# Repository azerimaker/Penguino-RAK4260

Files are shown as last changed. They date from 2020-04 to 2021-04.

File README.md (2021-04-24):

# Penguino-RAK4260
This repo contains all the necessary design and fabrication files for the Penguino 4260 SAMR34 Feather breakout board. 

First prototypes are being sold on [Tindie](https://www.tindie.com/products/21143/) and some more info can also be found on the corresponding [hackaday.io](https://hackaday.io/project/168876-penguino-feather-samr34-lora-dev-board) project page. This Penguino version uses [RAK4260](https://rakwireless.kckb.st/9e150da0) module. 

________________________________

### Current HW version is:
Penguino Feather v1.2. 
- Comes with green soldermask
- Adds CH340E USB-UART Converter IC

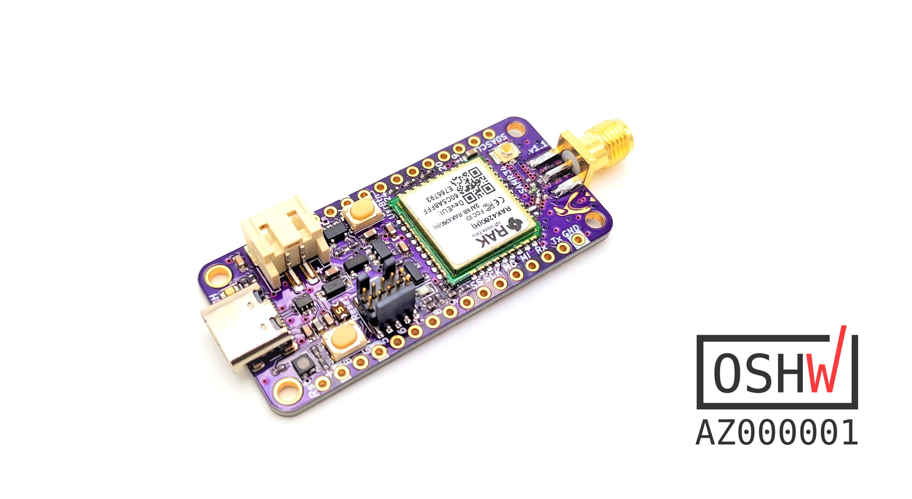
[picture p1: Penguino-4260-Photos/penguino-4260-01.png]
Penguino Feather Breakout v1.1


________________________________

### Example Firmware

Povided example in the *Firmware* directory contains ready to use example projetcs for Atmel Studio v7.
- RGB LED Toggle 
- LoRaWAN UART Demo

## License:
- Hardware license: CERN-OHL-S v2
- Software license: under MIT unless otherise indicated 
- Documentation license:  CC BY-SA 4.0 International.
________________________________
## Open Source Hardware
This board is an OSHWA approved design: [AZ000001](https://certification.oshwa.org/az000001.html)

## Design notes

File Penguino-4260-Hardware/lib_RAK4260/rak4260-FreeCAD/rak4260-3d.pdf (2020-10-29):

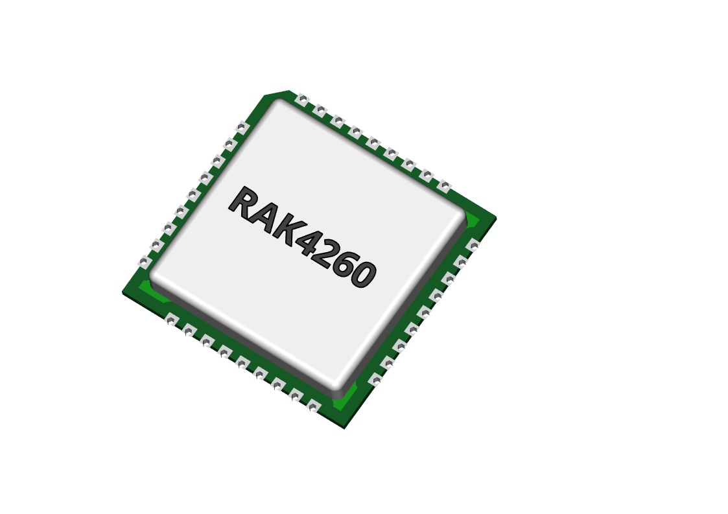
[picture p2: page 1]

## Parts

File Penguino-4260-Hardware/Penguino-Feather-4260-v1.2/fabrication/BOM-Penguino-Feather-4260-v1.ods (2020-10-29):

Name: | Penguino-Feather-4260-v1.2
Date:
Tool: | Eeschema (5.1.6)
Total Component Count: | 51
Unique Component Count: | 35
Item | Qty | Reference(s) | MPN | Alternative Part | Value | Footprint | URL | URL (alt)
1 | 3 | C1, C2, C3 | CL10A106MO8NQNC |  | 10uF | Capacitor_SMD:C_0603_1608Metric | https://lcsc.com/product-detail/Multilayer-Ceramic-Capacitors-MLCC-SMD-SMT_SAMSUNG_CL10A106MO8NQNC_10uF-106-20-16V_C92487.html | ~
2 | 3 | C4, C6, C9 | CC0603KRX7R9BB104 |  | 100nF | Capacitor_SMD:C_0603_1608Metric | https://lcsc.com/product-detail/Multilayer-Ceramic-Capacitors-MLCC-SMD-SMT_100nF-104-10-50V_C14663.html | ~
3 | 1 | C5 | GJM1555C1H470JB01D |  | 47pF | Capacitor_SMD:C_0402_1005Metric | https://lcsc.com/product-detail/Multilayer-Ceramic-Capacitors-MLCC-SMD-SMT_MuRata_GJM1555C1H470JB01D_47pF-470-5-50V_C161322.html | ~
4 |  | C7 | - |  | DNM | Capacitor_SMD:C_0402_1005Metric |  | ~
5 | 2 | C8, C12 | CC0603KRX7R9BB103 |  | 10nF | Capacitor_SMD:C_0603_1608Metric | https://lcsc.com/product-detail/Multilayer-Ceramic-Capacitors-MLCC-SMD-SMT_10nF-103-10-50V_C100042.html | ~
6 | 1 | C10 | CC0603KRX7R8BB105 |  | 1uF | Capacitor_SMD:C_0603_1608Metric | https://lcsc.com/product-detail/Others_YAGEO-CC0603KRX7R8BB105_C106858.html | ~
7 | 2 | C11, C13 | CC0402MRY5V8BB104 |  | 100nF | Capacitor_SMD:C_0402_1005Metric | https://lcsc.com/product-detail/Others_YAGEO-CC0402MRY5V8BB104_C327271.html | ~
8 | 1 | D1 | MBR0520 |  | MBR0520 | Diode_SMD:D_SOD-123 | https://lcsc.com/product-detail/Schottky-Barrier-Diodes-SBD_Changjiang-Electronics-Tech-CJ-MBR0520_C77335.html | ~
9 | 1 | D2 | 19-217/S2C-AL1M2VY/3T |  | CH_ORANGE | LED_SMD:LED_0603_1608Metric | https://lcsc.com/product-detail/Others_Everlight-Elec-19-217-S2C-AL1M2VY-3T_C264477.html | ~
10 | 1 | D3 | PGB1010402KR |  | PGB1010402 | Inductor_SMD:L_0402_1005Metric | https://lcsc.com/product-detail/Diodes-ESD_Littelfuse-PGB1010402KR_C10676.html | ~
11 | 1 | D4 | FC-DA1608BK-470H10 |  | PWR_BLUE | LED_SMD:LED_0603_1608Metric | https://lcsc.com/product-detail/Light-Emitting-Diodes-LED_Blue-light-SMDLED-80-100mcdatIF-10mA_C84266.html | ~
12 | 1 | D5 | FM-B2020RGBA-HG |  | RGB LED 2020 | LED_SMD:LED_Cree-PLCC4_2x2mm_CW | https://lcsc.com/product-detail/Light-Emitting-Diodes-LED_Foshan-NationStar-Optoelectronics-FM-B2020RGBA-HG_C108793.html | ~
13 | 1 | F1 | 0805L110SLYR |  | 1A | Fuse:Fuse_0805_2012Metric | https://lcsc.com/product-detail/Surface-Mount-Fuses_Littelfuse_0805L110SLYR_Littelfuse-0805L110SLYR_C207024.html | ~
14 | 1 | FB1 | BLM18HE152SN1D |  | BLM18HE152SN1D | Inductor_SMD:L_0603_1608Metric | https://lcsc.com/product-detail/Ferrite-Beads-And-Chips_muRata_BLM18HE152SN1D_1-5KR-25-at100MHz_C82155.html | ~
15 | 1 | J1 | U.FL-R-SMT-1(80) |  | U.FL-R-SMT-1 | Connector_Coaxial:U.FL_Hirose_U.FL-R-SMT-1_Vertical | https://lcsc.com/product-detail/_Hirose_U-FL-R-SMT-1-80_Hirose-HRS-U-FL-R-SMT-1-80_C88374.html | ~
16 | 1 | J2 | SMA-J-P-H-ST-EM1 |  | SMA-Edge-Mount | tinylora_v1:SMA_J_P_X_ST_EM1_EdgeMount | https://www.ebay.com/itm/293146230861 | ~
17 | 1 | J3 | TYPE-C-31-M-12 |  | USB_C_Receptacle_USB2.0 | Connector_USB:USB_C_Receptacle_Palconn_UTC16-G | https://lcsc.com/product-detail/USB-Connectors_Korean-Hroparts-Elec-TYPE-C-31-M-12_C165948.html | ~
18 | 1 | J4 | S2B-PH-SM4-TB(LF)(SN) |  | JST_PH | Connector_JST:JST_PH_S2B-PH-SM4-TB_1x02-1MP_P2.00mm_Horizontal | https://www.aliexpress.com/item/32513477927.html?spm=a2g0o.cart.0.0.696d3c00JbldTX | ~
19 | 1 | J5 | - | FTSH-105-01-F-DV-K | Male PCB Header Dual row | Connector_PinHeader_1.27mm:PinHeader_2x05_P1.27mm_Vertical_SMD | https://www.aliexpress.com/item/-/33030461496.html?spm=a2g0o.cart.0.0.24153c00ZQAOxm | https://www.digikey.com/product-detail/en/samtec-inc/FTSH-105-01-F-DV-K-TR/SAM13160CT-ND/8827915
20 | 1 | Q1 | SI2323DS-T1-E3 |  | SI2323DS | Package_TO_SOT_SMD:SOT-23 | https://lcsc.com/product-detail/MOSFET_Vishay-Intertech-SI2323DS-T1-E3_C141511.html | ~
21 |  | R1 | - | 0R | DNM | Resistor_SMD:R_0402_1005Metric | https://lcsc.com/product-detail/Chip-Resistor-Surface-Mount_0R-0R-5_C60485.html | ~
22 | 1 | R2 | RC0402JR-070RL |  | 0R | Resistor_SMD:R_0402_1005Metric | https://lcsc.com/product-detail/Chip-Resistor-Surface-Mount_0R-0R-5_C60485.html | ~
23 | 2 | R3, R5 | RC0402JR-07100KL |  | 100K | Resistor_SMD:R_0402_1005Metric | https://lcsc.com/product-detail/Chip-Resistor-Surface-Mount_100KR-104-5_C106234.html | ~
24 | 5 | R4, R7, R9, R10, R11 | RC0402FR-071K5L |  | 1K5 | Resistor_SMD:R_0402_1005Metric | https://lcsc.com/product-detail/Chip-Resistor-Surface-Mount_1-5KR-1501-1_C114759.html | ~
25 | 3 | R6, R13, R14 | RC0402FR-074K7L |  | 4K7 | Resistor_SMD:R_0402_1005Metric | https://lcsc.com/product-detail/Chip-Resistor-Surface-Mount_4-7KR-4701-1_C105871.html | ~
26 | 2 | R8, R17 | RC0402FR-0710KL |  | 10K | Resistor_SMD:R_0402_1005Metric | https://lcsc.com/product-detail/Chip-Resistor-Surface-Mount_YAGEO-RC0402FR-0710KL_C60490.html | ~
27 | 2 | R12, R15 | 0402WGF1004TCE |  | 1M | Resistor_SMD:R_0402_1005Metric | https://lcsc.com/product-detail/Chip-Resistor-Surface-Mount_Uniroyal-Elec-0402WGF1004TCE_C26083.html | ~
28 | 1 | R16 | RC0402JR-073M6L |  | 3M6 | Resistor_SMD:R_0402_1005Metric | https://lcsc.com/product-detail/Chip-Resistor-Surface-Mount_3-6MR-365-5_C137871.html | ~
29 | 2 | SW1, SW2 | SKRPACE010 |  | USR_BTN, RESET | switch-footprints:SW_Push_SKRPACE010 | https://lcsc.com/product-detail/Tactile-Switches_ALPS_SKRPACE010_SKRPACE010_C139797.html | ~
30 | 1 | U1 | MCP73831-2ACI-OT |  | LiPo battery charger IC | Package_TO_SOT_SMD:SOT-23-5 | https://lcsc.com/product-detail/PMIC-Battery-Management_Microchip-Tech-MCP73831T-2ACI-OT_C424093.html | ~
31 | 1 | U2 | S-1313D33 | ME6215C33 | +3.3V LDO Regulator | Package_TO_SOT_SMD:SOT-23-5 | https://lcsc.com/product-detail/Low-Dropout-Regulators-LDO_ME6215C33M5G_C84119.html | https://www.mouser.de/ProductDetail/ABLIC/S-1313C33-M5T1U3?qs=QrGA9tEX17PwWIi0dGVUlw==
32 | 1 | U3 | TPS3839K33DBZR | MAX809STRG | 3V Voltage Supervisor | Package_TO_SOT_SMD:SOT-23 | https://lcsc.com/product-detail/Microprocessor-Microcontroller-Supervisors_ON-Semicon_MAX809STRG_ON-Semicon-ON-MAX809STRG_C9965.html | https://lcsc.com/product-detail/PMIC-Supervisors_TI_TPS3839K33DBZR_TPS3839K33DBZR_C96333.html
33 | 1 | U4 | RAK4260 |  | RAK4260 | rak4260:RAK4260-footprint_w_solder_paste | https://store.rakwireless.com/products/rak4260-lora-module | ~
34 | 1 | U5 | NUP2202W1T2G |  | NUP2202 | Package_TO_SOT_SMD:SOT-363_SC-70-6 | https://lcsc.com/product-detail/TVS_ON-Semicon_NUP2202W1T2G_ON-Semicon-ON-NUP2202W1T2G_C89322.html | ~
35 | 1 | U7 | ATECC608A-TNGLORAS-B |  | TTN Secure Element | Package_SO:SOIC-8_3.9x4.9mm_P1.27mm | https://www.microchipdirect.com/product/ATECC608A-TNGLORA | ~
36 | 1 | U8 | W25Q16JVSS |  | 2MB Flash Memory | Package_SO:SOIC-8_5.23x5.23mm_P1.27mm | https://lcsc.com/product-detail/FLASH_Winbond-Elec-W25Q16JVSSIQ_C82317.html | ~
37 | 1 | U9 | CH340E |  | USB UART Converter | Package_SO:MSOP-10_3x3mm_P0.5mm

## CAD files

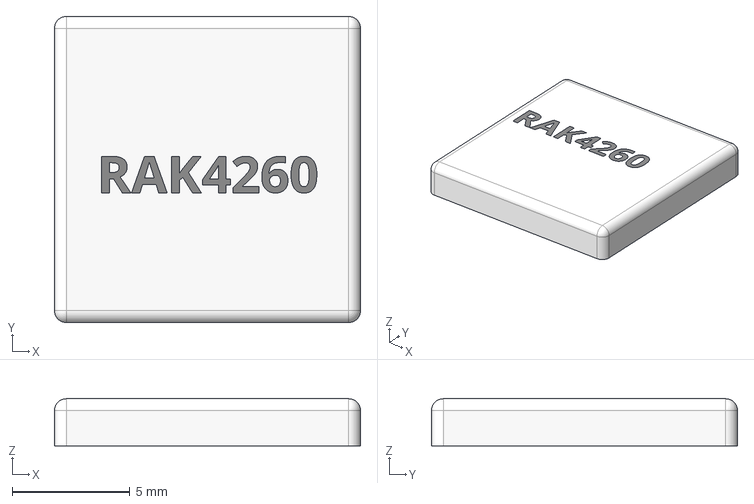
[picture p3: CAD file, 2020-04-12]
Penguino-4260-Hardware/lib_RAK4260/rak4260-FreeCAD/rak4260-freeCad.FCStd
13.0 x 13.0 x 3.00 mm
ShapeString

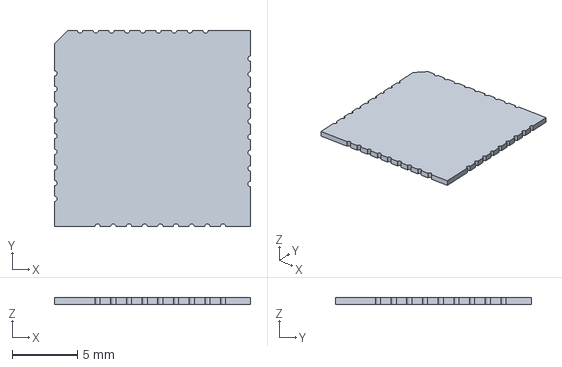
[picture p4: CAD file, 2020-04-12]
Penguino-4260-Hardware/lib_RAK4260/rak4260-pcb/radk4260-pcb.step
15.0 x 15.0 x 0.5 mm

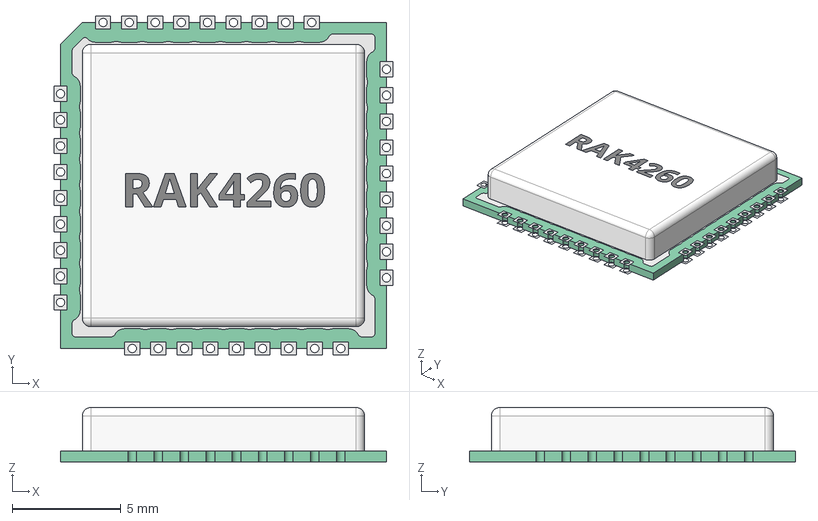
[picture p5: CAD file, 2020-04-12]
Penguino-4260-Hardware/lib_RAK4260/rak4260-FreeCAD/rak4260-freeCad-2.FCStd
15.6 x 15.6 x 2.57 mm
Pcb
topTracks
ShapeString
botTracks001

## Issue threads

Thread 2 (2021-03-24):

Battery voltage

henriAbel, 2021-03-24:
I have been experimenting with reading battery voltage using both Mbed OS and ASF framework but have not been able to get correct results. There seems to be some ADC init error in Mbed OS, I always get 0xFF as voltage. In ASF I was able to get ADC to measure something. Initially I got also max voltage but then i discovered that if i measure with multimeter between JP4 and GND and at the same time look the ADC measurement then voltage seems to be correct. I was able to reproduce same result with previous version of this board. Is there some internal pull-ups that i should disable for PA08 pin?

azerimaker, 2021-03-25:
Dear @henriAbel, thank you for bringing up this issue.
To be honest, I've never tried the ADC myself. I suspect this might be due to the selection of the reference voltage.
I would suggest using the [BastWAN sensor example](https://github.com/ElectronicCats/BastWAN/tree/master/Examples/LoRaWAN/lorawan_sensors) with Arduino IDE and see if you're able to get correct readings. There's an example sketch with ADC read function. Whenever I get I chance, I'll also look into that.

henriAbel, 2021-04-03:
BastWAN sensor example does not use ADC, just generates random values. But i flashed BastWAN Arduino core to the Penguino board and got correct results. So the problem is in my ASF code, have to poke around litte bit more.

Closed 2021-04-03.

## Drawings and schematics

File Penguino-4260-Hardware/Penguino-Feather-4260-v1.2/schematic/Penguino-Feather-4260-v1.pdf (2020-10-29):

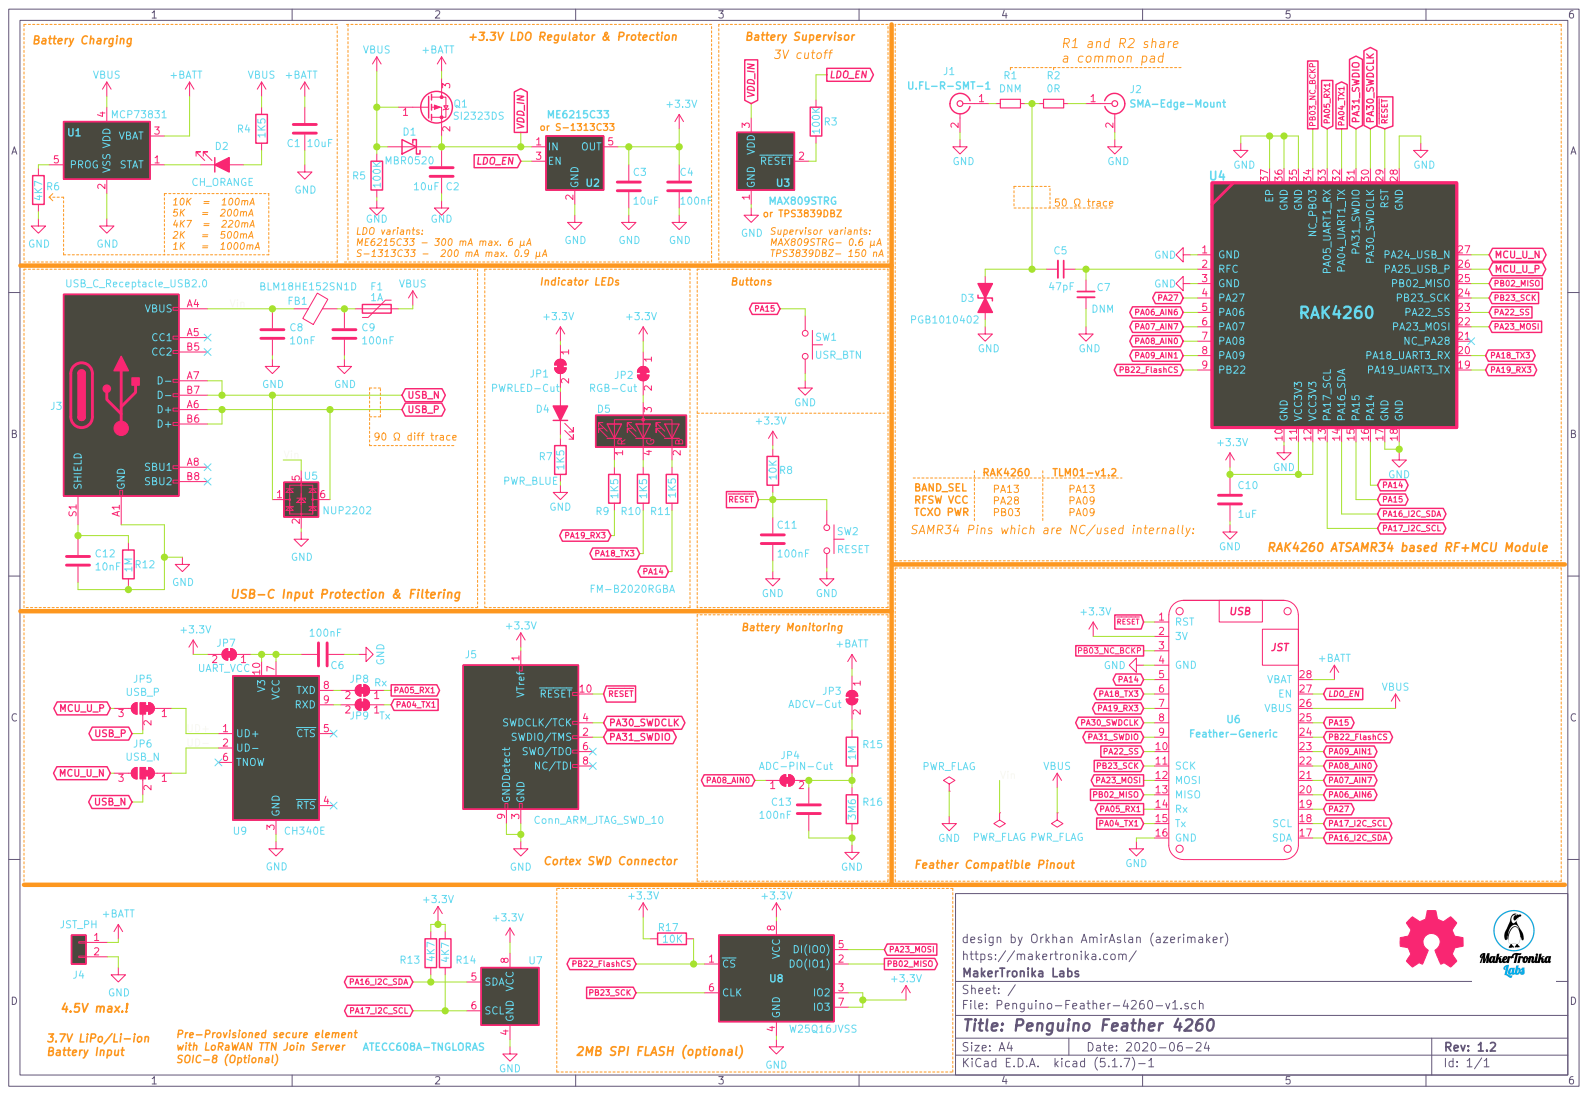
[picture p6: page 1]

50 trace Battery Supervisor Buttons Battery Charging

2 EN 3 OUT 5 U2 ME6215C33 STAT 1 VSS

USB-C Input Protection & Filtering

3 RTS 4 CTS 5 TNOW 6 VCC

3 SWDCLK/TCK 4 SWO/TDO 6 NC/TDI 8 GNDDetect 9

design by Orkhan AmirAslan (azerimaker) C13

https://makertronika.com/
File: Penguino-Feather-4260-v1.sch Sheet: / MakerTronika Labs

Id: 1/1 Title: Penguino Feather 4260

Pre-Provisioned secure element with LoRaWAN TTN Join Server SOIC-8 (Optional)

3.7V LiPo/Li-ion Battery Input

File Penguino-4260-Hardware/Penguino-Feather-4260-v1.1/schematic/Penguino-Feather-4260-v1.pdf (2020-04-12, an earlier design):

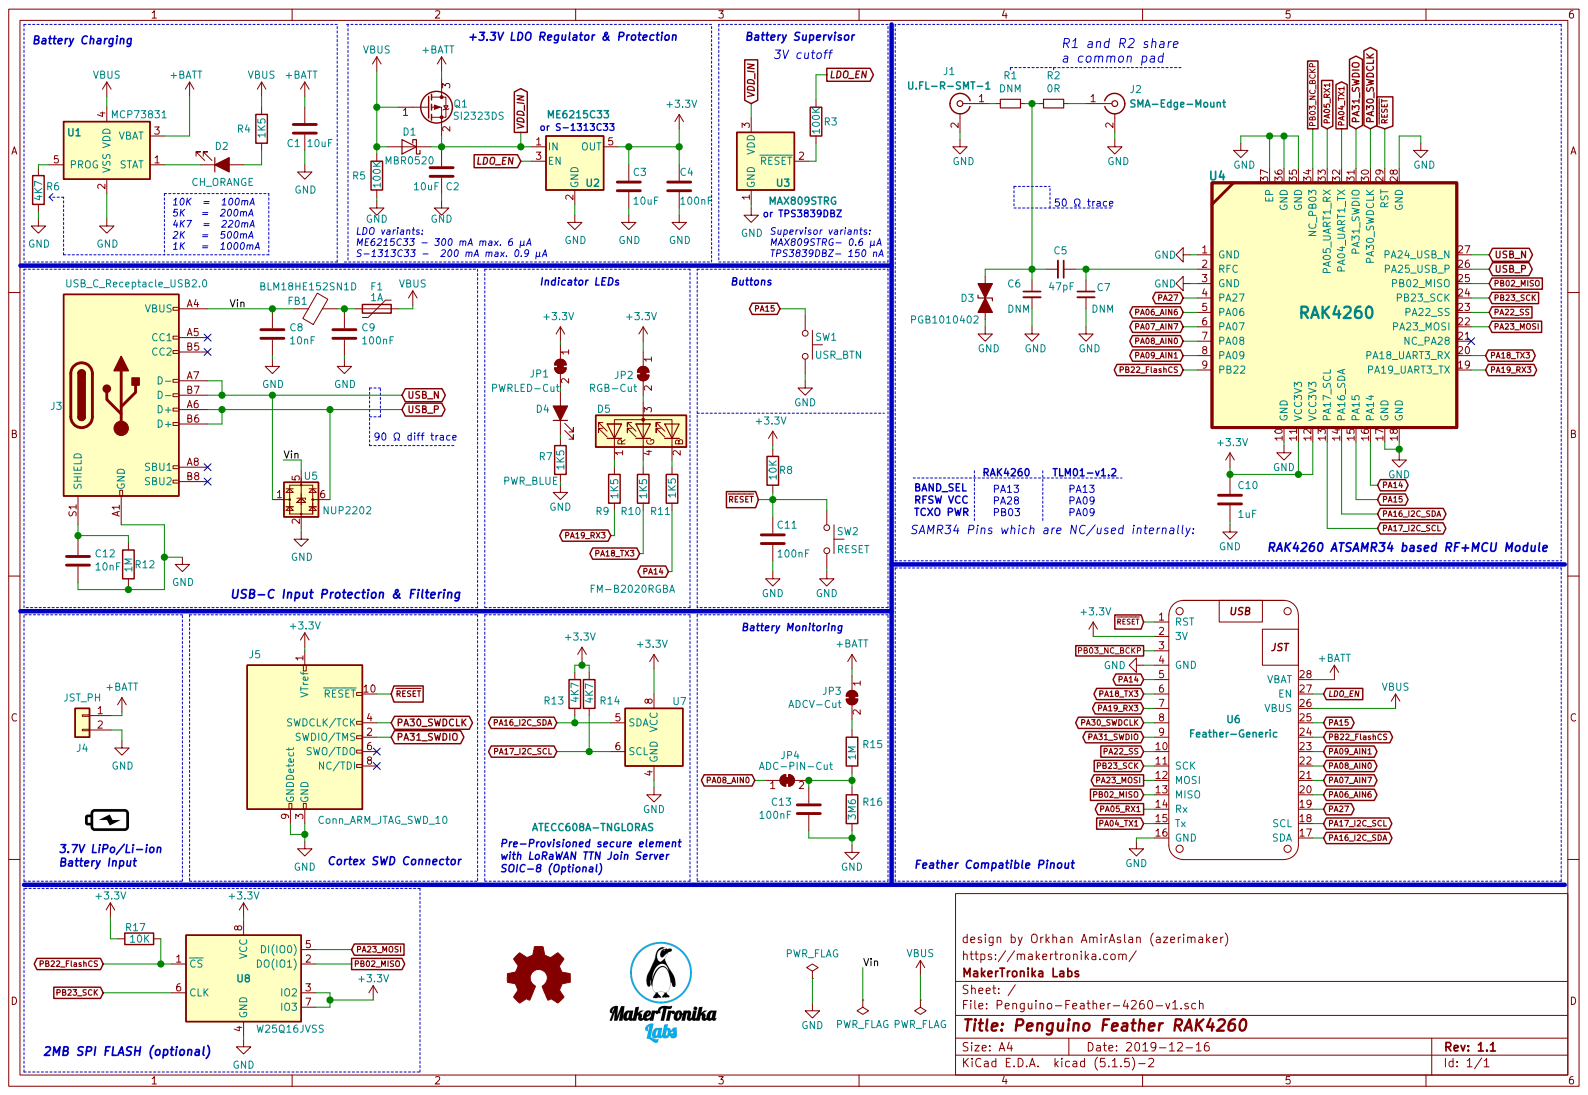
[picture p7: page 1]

2 EN 3 OUT 5 U2 ME6215C33 GND GND GND GND GND GND GND

USB-C Input Protection & Filtering

3 SWDCLK/TCK 4 SWO/TDO 6 NC/TDI 8 GNDDetect 9

3.7V LiPo/Li-ion Battery Input

design by Orkhan AmirAslan (azerimaker)
https://makertronika.com/
File: Penguino-Feather-4260-v1.sch Sheet: / MakerTronika Labs

Id: 1/1 Title: Penguino Feather RAK4260

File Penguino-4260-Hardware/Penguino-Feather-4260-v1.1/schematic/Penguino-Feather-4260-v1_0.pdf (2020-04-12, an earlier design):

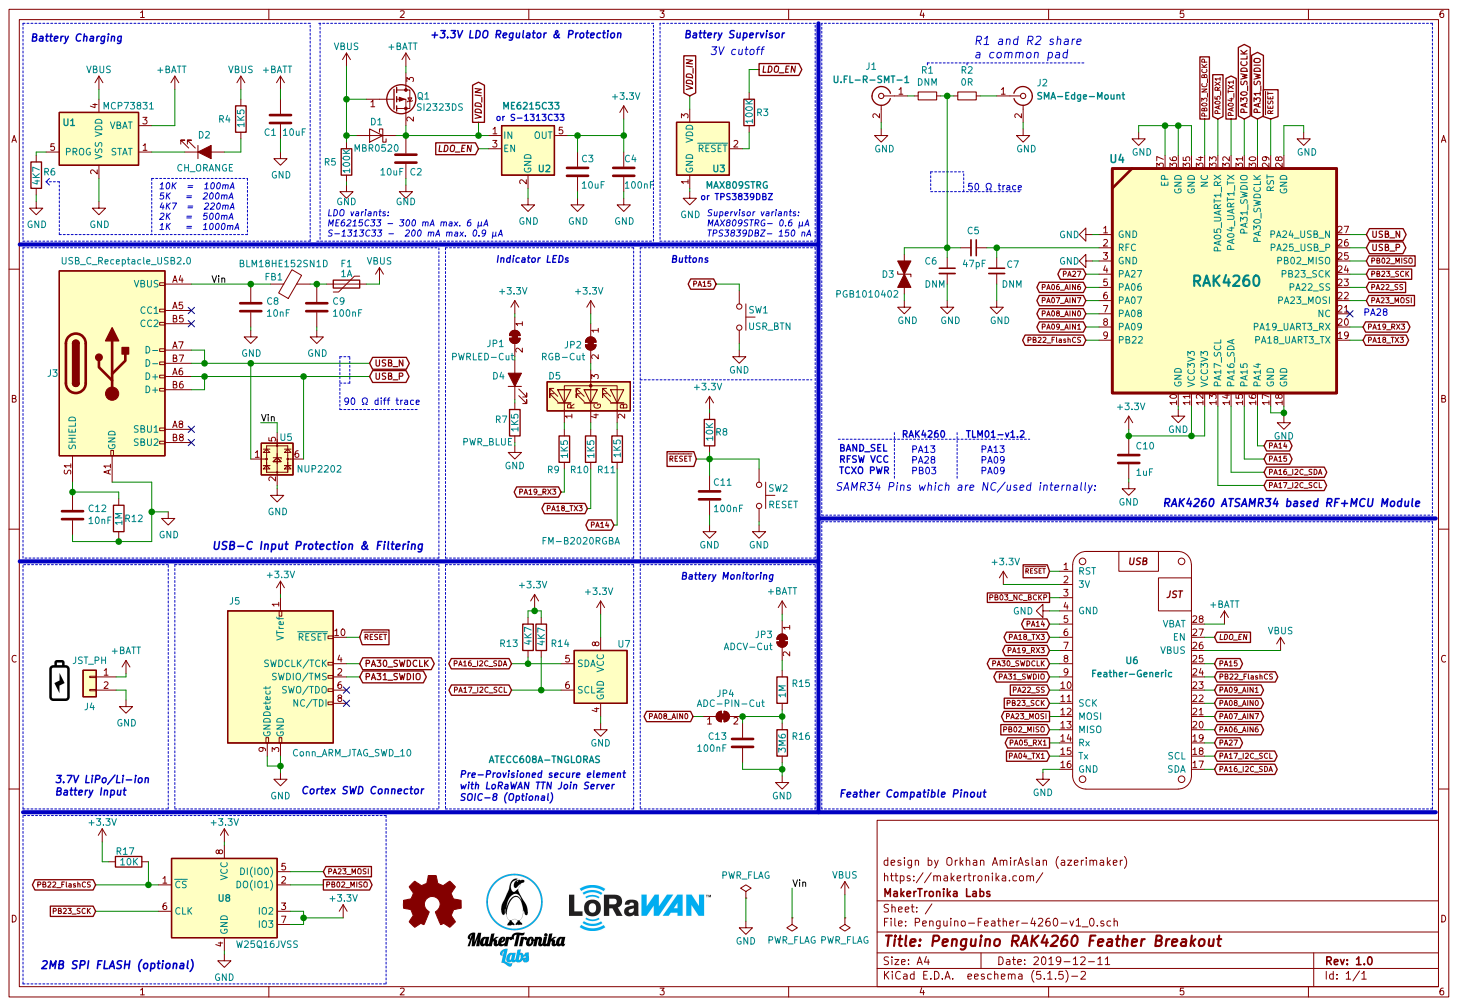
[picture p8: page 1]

2 EN 3 OUT 5 U2 ME6215C33 STAT 1 VSS

design by Orkhan AmirAslan (azerimaker) GND

JP2 RGB-Cut +BATT GND

USB-C Input Protection & Filtering

3 SWDCLK/TCK 4 SWO/TDO 6 NC/TDI 8 GNDDetect 9

3.7V LiPo/Li-ion Battery Input

https://makertronika.com/
File: Penguino-Feather-4260-v1_0.sch Sheet: / MakerTronika Labs

Id: 1/1 Title: Penguino RAK4260 Feather Breakout

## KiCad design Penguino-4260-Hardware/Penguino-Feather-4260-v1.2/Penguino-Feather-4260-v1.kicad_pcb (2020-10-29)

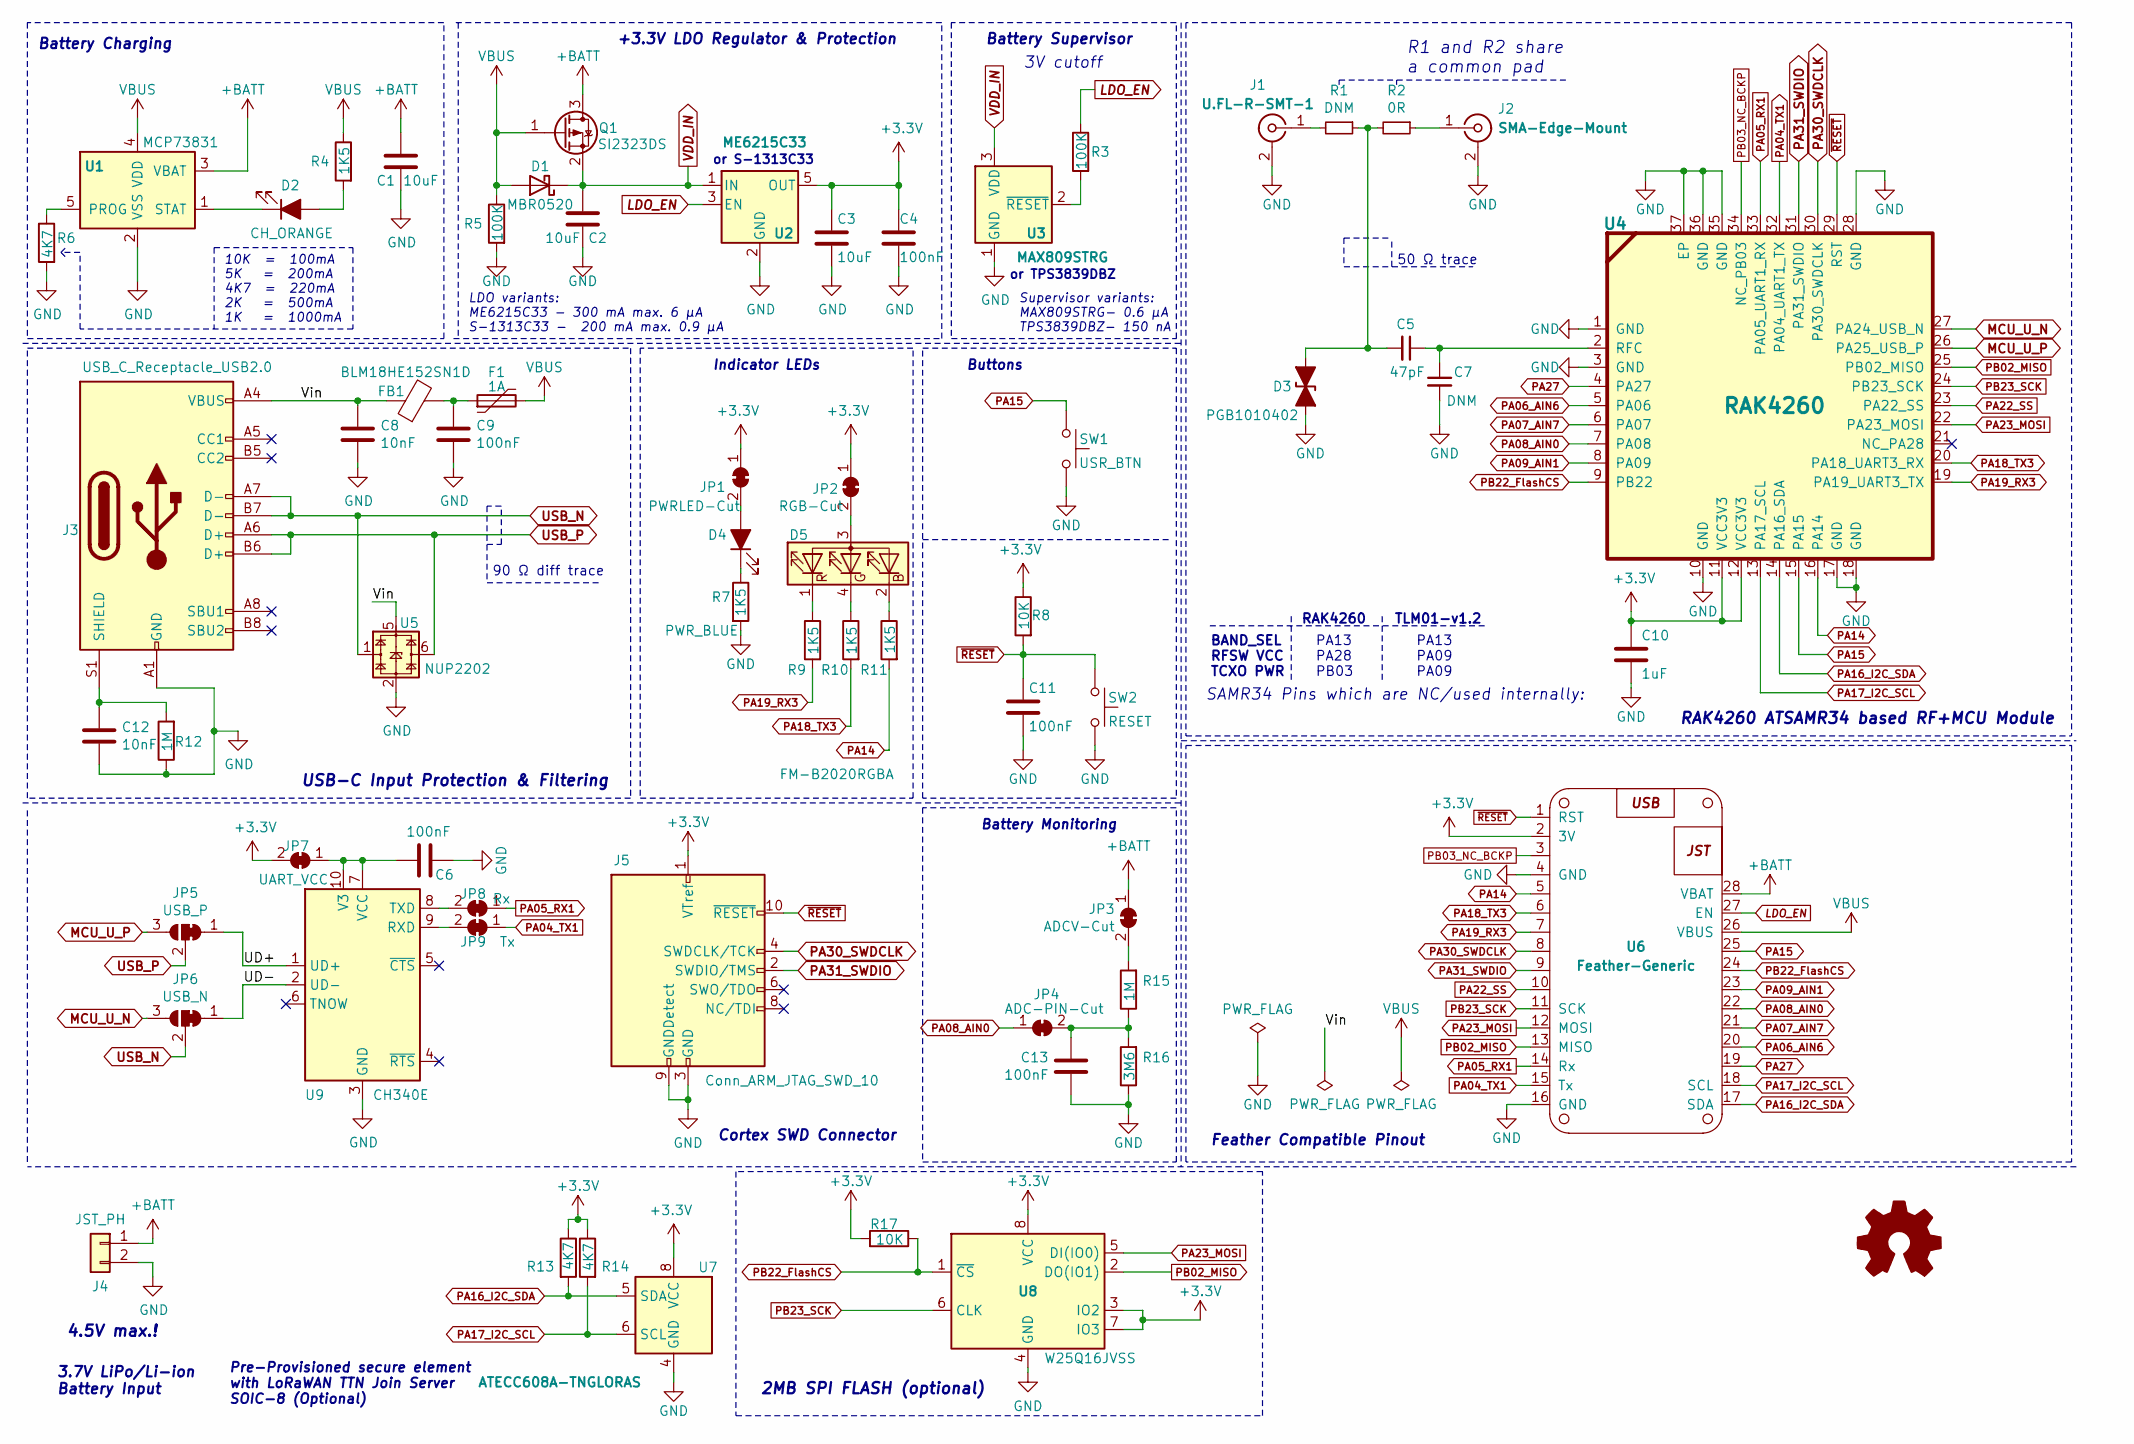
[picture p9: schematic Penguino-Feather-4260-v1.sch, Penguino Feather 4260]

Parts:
C1, C2, C3: 10uF; C_0603_1608Metric
C4, C6, C9: 100nF; C_0603_1608Metric; MPN CC0603KRX7R9BB104
C5: 47pF; C_0402_1005Metric
C7: DNM; C_0402_1005Metric
C8, C12: 10nF; C_0603_1608Metric; MPN CC0603KRX7R9BB103
C10: 1uF; C_0603_1608Metric; MPN CC0603KRX7R8BB105
C11, C13: 100nF; C_0402_1005Metric; MPN CC0603KRX7R9BB104
D1: MBR0520; D_SOD-123; MPN MBR0520
D2: CH_ORANGE; LED_0603_1608Metric
D3: PGB1010402; L_0402_1005Metric; MPN PGB1010402KR
D4: PWR_BLUE; LED_0603_1608Metric
D5: FM-B2020RGBA; LED_Cree-PLCC4_2x2mm_CW; MPN FM-B2020RGBA-HG
F1: 1A; Fuse_0805_2012Metric; MPN 0805L110SLYR
FB1: BLM18HE152SN1D; L_0603_1608Metric; MPN BLM18HE152SN1D
J1: U.FL-R-SMT-1; U.FL_Hirose_U.FL-R-SMT-1_Vertical; MPN U.FL-R-SMT-1(80)
J2: SMA-Edge-Mount; SMA_J_P_X_ST_EM1_EdgeMount; MPN SMA-J-P-H-ST-EM1
J3: USB_C_Receptacle_USB2.0; USB_C_Receptacle_Palconn_UTC16-G; MPN TYPE-C-31-M-12
J4: JST_PH; JST_PH_S2B-PH-SM4-TB_1x02-1MP_P2.00mm_Horizontal; MPN S2B-PH-SM4-TB(LF)(SN)
J5: Conn_ARM_JTAG_SWD_10; PinHeader_2x05_P1.27mm_Vertical_SMD
JP1: PWRLED-Cut; SolderJumper-2_P1.3mm_Bridged_RoundedPad1.0x1.5mm
JP2: RGB-Cut; SolderJumper-2_P1.3mm_Bridged_RoundedPad1.0x1.5mm
JP3: ADCV-Cut; SolderJumper-2_P1.3mm_Bridged_RoundedPad1.0x1.5mm
JP4: ADC-PIN-Cut; SolderJumper-2_P1.3mm_Bridged_RoundedPad1.0x1.5mm
JP5: USB_P; SolderJumper-3_P1.3mm_Bridged12_Pad1.0x1.5mm
JP6: USB_N; SolderJumper-3_P1.3mm_Bridged12_Pad1.0x1.5mm
JP7: UART_VCC; SolderJumper-2_P1.3mm_Bridged_RoundedPad1.0x1.5mm
JP8: Rx; SolderJumper-2_P1.3mm_Bridged_RoundedPad1.0x1.5mm
JP9: Tx; SolderJumper-2_P1.3mm_Bridged_RoundedPad1.0x1.5mm
Q1: SI2323DS; SOT-23; MPN SI2323DS-T1-E3
R1: DNM; R_0402_1005Metric
R2: 0R; R_0402_1005Metric
R3, R5: 100K; R_0402_1005Metric
R4, R7, R9, R10, R11: 1K5; R_0402_1005Metric
R6, R13, R14: 4K7; R_0402_1005Metric
R8, R17: 10K; R_0402_1005Metric
R12, R15: 1M; R_0402_1005Metric
R16: 3M6; R_0402_1005Metric; MPN RC0402JR-073M6L
SW1: USR_BTN; SW_Push_SKRPACE010; MPN SKRPACE010
SW2: RESET; SW_Push_SKRPACE010; MPN SKRPACE010
U1: MCP73831; SOT-23-5; MPN MCP73831-2-OT
U2: ME6215C33; SOT-23-5; MPN ME6215C33
U3: MAX809STRG; SOT-23; MPN MAX809STRG
U4: RAK4260; RAK4260-footprint_w_solder_paste
U5: NUP2202; SOT-363_SC-70-6; MPN NUP2202W1T2G
U6: Feather-Generic
U7: ATECC608A-TNGLORAS; SOIC-8_3.9x4.9mm_P1.27mm; MPN ATECC608A-TNGLORAS-B
U8: W25Q16JVSS; SOIC-8_5.23x5.23mm_P1.27mm
U9: CH340E; MSOP-10_3x3mm_P0.5mm

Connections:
+3V3: C3.1, C4.1, C10.1, J5.1 (VTref), JP1.1 (A), JP2.1 (A), JP7.2 (B), R8.1, R13.1, R14.1, R17.2, U2.5 (OUT), U4.11 (VCC3V3), U4.12 (VCC3V3), U6.2 (3V), U7.8 (VCC), U8.3 (IO2), U8.7 (IO3), U8.8 (VCC)
+BATT: C1.1, J4.1, JP3.1 (A), Q1.3 (D), U1.3 (VBAT), U6.28 (VBAT)
/UD+: JP5.1 (A), U9.1 (UD+)
/UD-: JP6.1 (A), U9.2 (UD-)
/Vin: C8.1, FB1.1, J3.A4 (VBUS), J3.A9 (VBUS), J3.B4 (VBUS), J3.B9 (VBUS), U5.5
GND: C1.2, C2.2, C3.2, C4.2, C6.1, C7.2, C8.2, C9.2, C10.2, C11.2, C12.1, C13.1, D3.2 (A2), J1.2 (Ext), J2.2 (Ext), J3.A1 (GND), J3.A12 (GND), J3.B1 (GND), J3.B12 (GND), J4.2, J5.3 (GND), J5.5 (GND), J5.9 (GNDDetect), R5.2, R6.2, R7.2, R12.1, R16.1, SW1.1, SW2.1, U1.2 (VSS), U2.2 (GND), U3.1 (GND), U4.1 (GND), U4.3 (GND), U4.10 (GND), U4.17 (GND), U4.18 (GND), U4.28 (GND), U4.35 (GND), U4.36 (GND), U4.37 (EP), U5.2, U6.4 (GND), U6.16 (GND), U7.4 (GND), U8.4 (GND), U9.3 (GND)
LDO_EN: R3.1, U2.3 (EN), U6.27 (EN)
MCU_U_N: JP6.3 (B), U4.27 (PA24_USB_N)
MCU_U_P: JP5.3 (B), U4.26 (PA25_USB_P)
unnamed: C5.1, C7.1, U4.2 (RFC)
unnamed: C5.2, D3.1 (A1), R1.1, R2.2
unnamed: C6.2, JP7.1 (A), U9.7 (VCC), U9.10 (V3)
unnamed: C9.1, F1.1, FB1.2
unnamed: C12.2, J3.S1 (SHIELD), R12.2
unnamed: C13.2, JP4.2 (B), R15.1, R16.2
unnamed: D2.1 (K), U1.1 (STAT)
unnamed: D2.2 (A), R4.2
unnamed: D4.1 (K), R7.1
unnamed: D4.2 (A), JP1.2 (B)
unnamed: D5.1 (RK), R9.1
unnamed: D5.2 (BK), R11.1
unnamed: D5.3 (A), JP2.2 (B)
unnamed: D5.4 (GK), R10.1
unnamed: J1.1 (In), R1.2
unnamed: J2.1 (In), R2.1
unnamed: JP3.2 (B), R15.2
unnamed: JP8.2 (B), U9.8 (TXD)
unnamed: JP9.2 (B), U9.9 (RXD)
unnamed: R3.2, U3.2 (~RESET)
unnamed: R6.1, U1.5 (PROG)
PA04_TX1: JP9.1 (A), U4.32 (PA04_UART1_TX), U6.15 (Tx)
PA05_RX1: JP8.1 (A), U4.33 (PA05_UART1_RX), U6.14 (Rx)
PA06_AIN6: U4.5 (PA06), U6.20
PA07_AIN7: U4.6 (PA07), U6.21
PA08_AIN0: JP4.1 (A), U4.7 (PA08), U6.22
PA09_AIN1: U4.8 (PA09), U6.23
PA14: R11.2, U4.16 (PA14), U6.5
PA15: SW1.2, U4.15 (PA15), U6.25
PA16_I2C_SDA: R13.2, U4.14 (PA16_SDA), U6.17 (SDA), U7.5 (SDA)
PA17_I2C_SCL: R14.2, U4.13 (PA17_SCL), U6.18 (SCL), U7.6 (SCL)
PA18_TX3: R10.2, U4.20 (PA18_UART3_RX), U6.6
PA19_RX3: R9.2, U4.19 (PA19_UART3_TX), U6.7
PA22_SS: U4.23 (PA22_SS), U6.10
PA23_MOSI: U4.22 (PA23_MOSI), U6.12 (MOSI), U8.5 (DI(IO0))
PA27: U4.4 (PA27), U6.19
PA30_SWDCLK: J5.4 (SWDCLK/TCK), U4.30 (PA30_SWDCLK), U6.8
PA31_SWDIO: J5.2 (SWDIO/TMS), U4.31 (PA31_SWDIO), U6.9
PB02_MISO: U4.25 (PB02_MISO), U6.13 (MISO), U8.2 (DO(IO1))
PB03_NC_BCKP: U4.34 (NC_PB03), U6.3
PB22_FlashCS: R17.1, U4.9 (PB22), U6.24, U8.1 (~CS)
PB23_SCK: U4.24 (PB23_SCK), U6.11 (SCK), U8.6 (CLK)
USB_N: J3.A7 (D-), J3.B7 (D-), JP6.2 (C), U5.1
USB_P: J3.A6 (D+), J3.B6 (D+), JP5.2 (C), U5.6
VBUS: D1.2 (A), F1.2, Q1.1 (G), R4.1, R5.1, U1.4 (VDD), U6.26 (VBUS)
VDD_IN: C2.1, D1.1 (K), Q1.2 (S), U2.1 (IN), U3.3 (VDD)
~RESET: C11.1, J5.10 (~RESET~), R8.2, SW2.2, U4.29 (RST), U6.1 (RST)

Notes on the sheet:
10K = 100mA 5K = 200mA 4K7 = 220mA 2K = 500mA 1K = 1000mA
3.7V LiPo/Li-ion Battery Input
Battery Charging
USB-C Input Protection & Filtering
Indicator LEDs
RAK4260 ATSAMR34 based RF+MCU Module
Feather Compatible Pinout
Battery Monitoring
R1 and R2 share a common pad
Cortex SWD Connector
90 Ω diff trace
50 Ω trace
SAMR34 Pins which are NC/used internally:
Pre-Provisioned secure element with LoRaWAN TTN Join Server SOIC-8 (Optional)
Buttons
+3.3V LDO Regulator & Protection
Battery Supervisor
LDO variants: ME6215C33 - 300 mA max. 6 μA S-1313C33 - 200 mA max. 0.9 μA
3V cutoff
or TPS3839DBZ
or S-1313C33
Supervisor variants: MAX809STRG- 0.6 μA TPS3839DBZ- 150 nA
2MB SPI FLASH (optional)
BAND_SEL RFSW VCC TCXO PWR
PA13 PA28 PB03
PA13 PA09 PA09
RAK4260 TLM01-v1.2
4.5V max.!

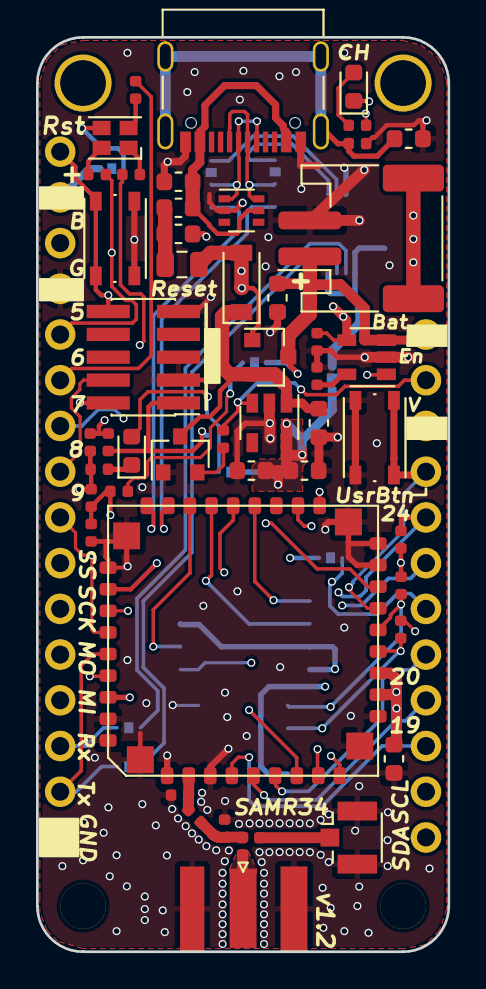
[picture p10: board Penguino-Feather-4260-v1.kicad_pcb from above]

Board: 4 copper layers, 22.9 x 50.8 mm, 63 parts (0 on the bottom side), 56 nets.

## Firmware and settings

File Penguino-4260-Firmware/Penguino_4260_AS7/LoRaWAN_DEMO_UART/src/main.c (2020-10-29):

/**
* \file  main.c
*
* \brief LORAWAN Demo Application main file
*		
*
* Copyright (c) 2018 Microchip Technology Inc. and its subsidiaries. 
*
* \asf_license_start
*
* \page License
*
* Subject to your compliance with these terms, you may use Microchip
* software and any derivatives exclusively with Microchip products. 
* It is your responsibility to comply with third party license terms applicable 
* to your use of third party software (including open source software) that 
* may accompany Microchip software.
*
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
* \asf_license_stop
*
*/
/*
* Support and FAQ: visit <a href="https://www.microchip.com/support/">Microchip Support</a>
*/
 
/****************************** INCLUDES **************************************/
#include "system_low_power.h"
#include "radio_driver_hal.h"
#include "lorawan.h"
#include "sys.h"
#include "system_init.h"
#include "system_assert.h"
#include "aes_engine.h"
#include "enddevice_demo.h"
#include "sio2host.h"
#include "extint.h"
#include "conf_app.h"
#include "sw_timer.h"
#include "nvm.h"
#ifdef CONF_PMM_ENABLE
#include "pmm.h"
#include  "conf_pmm.h"
#include "sleep_timer.h"
#include "sleep.h"
#endif
#include "conf_sio2host.h"
#if (ENABLE_PDS == 1)
#include "pds_interface.h"
#endif
#if (CERT_APP == 1)
#include "conf_certification.h"
#include "enddevice_cert.h"
#endif
/************************** Macro definition ***********************************/
/* Button debounce time in ms */
#define APP_DEBOUNCE_TIME       50
/************************** Global variables ***********************************/
bool button_pressed = false;
bool factory_reset = false;
bool bandSelected = false;
uint32_t longPress = 0;
uint8_t demoTimerId = 0xFF;
uint8_t lTimerId = 0xFF;
extern bool certAppEnabled;
#ifdef CONF_PMM_ENABLE
bool deviceResetsForWakeup = false;
#endif
/************************** Extern variables ***********************************/

/************************** Function Prototypes ********************************/
static void driver_init(void);

#if (_DEBUG_ == 1)
static void assertHandler(SystemAssertLevel_t level, uint16_t code);
#endif /* #if (_DEBUG_ == 1) */

/*********************************************************************//**
 \brief      Uninitializes app resources before going to low power mode
*************************************************************************/
#ifdef CONF_PMM_ENABLE
static void app_resources_uninit(void);
#endif

/****************************** FUNCTIONS **************************************/

static void print_reset_causes(void)
{
    enum system_reset_cause rcause = system_get_reset_cause();
    printf("Last reset cause: ");
    if(rcause & (1 << 6)) {
        printf("System Reset Request\r\n");
    }
    if(rcause & (1 << 5)) {
        printf("Watchdog Reset\r\n");
    }
    if(rcause & (1 << 4)) {
        printf("External Reset\r\n");
    }
    if(rcause & (1 << 2)) {
        printf("Brown Out 33 Detector Reset\r\n");
    }
    if(rcause & (1 << 1)) {
        printf("Brown Out 12 Detector Reset\r\n");
    }
    if(rcause & (1 << 0)) {
        printf("Power-On Reset\r\n");
    }
}

#ifdef CONF_PMM_ENABLE
static void appWakeup(uint32_t sleptDuration)
{
    HAL_Radio_resources_init();
    sio2host_init();
    printf("\r\nsleep_ok %ld ms\r\n", sleptDuration);

}
#endif

#if (_DEBUG_ == 1)
static void assertHandler(SystemAssertLevel_t level, uint16_t code)
{
    printf("\r\n%04x\r\n", code);
    (void)level;
}
#endif /* #if (_DEBUG_ == 1) */

/**
 * \mainpage
 * \section preface Preface
 * This is the reference manual for the LORAWAN Demo Application of EU Band
 */
int main(void)
{
    /* System Initialization */
    system_init();
    /* Initialize the delay driver */
    delay_init();
    /* Initialize the board target resources */
    board_init();

    INTERRUPT_GlobalInterruptEnable();
    /* Initialize Hardware and Software Modules */
    driver_init();
    /* Initialize the Serial Interface */
    sio2host_init();

    print_reset_causes();
#if (_DEBUG_ == 1)
    SYSTEM_AssertSubscribe(assertHandler);
#endif
    /* Initialize demo application */
    Stack_Init();

    SwTimerCreate(&demoTimerId);
    SwTimerCreate(&lTimerId);

    mote_demo_init();

/*struct nvm_fusebits fb;
nvm_get_fuses(&fb);
printf("\nPAC->WRCTRL.reg:%x\r\n",PAC->WRCTRL.reg);
printf("\nNVMCTRL_USER:%x\r\n",*(uint32_t *)NVMCTRL_USER);
fb.wdt_enable = 0;
fb.wdt_always_on = 0;
nvm_set_fuses(&fb);
printf("\nNVMCTRL_USER:%x\r\n",*(uint32_t *)NVMCTRL_USER);
WDT->CTRLA.reg &= 0x0;
WDT->CTRLA.reg &= 0x0;
WDT->CTRLA.reg &= 0x0;
WDT->CTRLA.reg &= 0x0;


printf("\nWDT->CTRLA.reg:%x\r\n",WDT->CTRLA.reg);*/

    while (1)
    {
		serial_data_handler();
        SYSTEM_RunTasks();
#ifdef CONF_PMM_ENABLE
        if (false == certAppEnabled)
        {
            if(bandSelected == true)
            {
                PMM_SleepReq_t sleepReq;
                /* Put the application to sleep */
                sleepReq.sleepTimeMs = DEMO_CONF_DEFAULT_APP_SLEEP_TIME_MS;
                sleepReq.pmmWakeupCallback = appWakeup;
                sleepReq.sleep_mode = CONF_PMM_SLEEPMODE_WHEN_IDLE;
                if (CONF_PMM_SLEEPMODE_WHEN_IDLE == SLEEP_MODE_STANDBY)
                {
                    deviceResetsForWakeup = false;
                }
                if (true == LORAWAN_ReadyToSleep(deviceResetsForWakeup))
                {
                    app_resources_uninit();
                    if (PMM_SLEEP_REQ_DENIED == PMM_Sleep(&sleepReq))
                    {
                        HAL_Radio_resources_init();
                        sio2host_init();
                        /*printf("\r\nsleep_not_ok\r\n");*/
                    }
                }
            }
        }
#endif
    }
}

/* Initializes all the hardware and software modules used for Stack operation */
static void driver_init(void)
{
    /* Initialize the Radio Hardware */
    HAL_RadioInit();
    /* Initialize the AES Hardware Engine */
    AESInit();
    /* Initialize the Software Timer Module */
    SystemTimerInit();
#ifdef CONF_PMM_ENABLE
    /* Initialize the Sleep Timer Module */
    SleepTimerInit();
#endif
#if (ENABLE_PDS == 1)
    /* PDS Module Init */
    PDS_Init();
#endif
}

#ifdef CONF_PMM_ENABLE
static void app_resources_uninit(void)
{
    /* Disable USART TX and RX Pins */
    struct port_config pin_conf;
    port_get_config_defaults(&pin_conf);
    pin_conf.powersave  = true;
    port_pin_set_config(HOST_SERCOM_PAD0_PIN, &pin_conf);
    port_pin_set_config(HOST_SERCOM_PAD1_PIN, &pin_conf);
    /* Disable UART module */
    sio2host_deinit();
    /* Disable Transceiver SPI Module */
    HAL_RadioDeInit();
}
#endif
/**
 End of File
 */

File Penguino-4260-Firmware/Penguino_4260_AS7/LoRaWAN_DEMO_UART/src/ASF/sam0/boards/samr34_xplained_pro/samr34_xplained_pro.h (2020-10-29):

/**
 * \file
 *
 * \brief SAM R34 Xplained Pro board definition
 *
 * Copyright (c) 2016-2018 Microchip Technology Inc. and its subsidiaries.
 *
 * \asf_license_start
 *
 * \page License
 *
 * Subject to your compliance with these terms, you may use Microchip
 * software and any derivatives exclusively with Microchip products.
 * It is your responsibility to comply with third party license terms applicable
 * to your use of third party software (including open source software) that
 * may accompany Microchip software.
 *
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
 * \asf_license_stop
 *
 */
/*
 * Support and FAQ: visit <a href="https://www.microchip.com/support/">Microchip Support</a>
 */

#ifndef SAMR34_XPLAINED_PRO_H_INCLUDED
#define SAMR34_XPLAINED_PRO_H_INCLUDED

#include <conf_board.h>
#include <compiler.h>

#ifdef __cplusplus
extern "C" {
#endif

/**
 * \ingroup group_common_boards
 * \defgroup samr34_xplained_pro_group SAM R34 Xplained Pro board
 *
 * @{
 */

void system_board_init(void);

/**
 * \defgroup samr34xplained_pro_features_group Features
 *
 * Symbols that describe features and capabilities of the board.
 *
 * @{
 */

/** Name string macro */
#define BOARD_NAME                "SAMR34_XPLAINED_PRO"

/** \name Resonator definitions
 *  @{ */
#define BOARD_FREQ_SLCK_XTAL      (32768U)
#define BOARD_FREQ_SLCK_BYPASS    (32768U)
#define BOARD_FREQ_MAINCK_XTAL    0 /* Not Mounted */
#define BOARD_FREQ_MAINCK_BYPASS  0 /* Not Mounted */
#define BOARD_MCK                 CHIP_FREQ_CPU_MAX
#define BOARD_OSC_STARTUP_US      15625
/** @} */

/** \name LED0 definitions
 *  @{ */
#define LED0_PIN                  PIN_PA19
#define LED0_ACTIVE               false
#define LED0_INACTIVE             !LED0_ACTIVE
/** @} */

/** \name LED1 definitions
 *  @{ */
#define LED1_PIN                  PIN_PA18
#define LED1_ACTIVE               false
#define LED1_INACTIVE             !LED1_ACTIVE
/** @} */

/** \name SW0 definitions
 *  @{ */
/*#define SW0_PIN                   PIN_PA28
#define SW0_ACTIVE                false
#define SW0_INACTIVE              !SW0_ACTIVE
#define SW0_EIC_PIN               PIN_PA28
#define SW0_EIC_MUX               MUX_PA28A_EIC_EXTINT8
#define SW0_EIC_PINMUX            PINMUX_PA28A_EIC_EXTINT8
#define SW0_EIC_LINE              8*/
/** @} */

/** \name RF SWITCH definitions
 *  @{ */
#define RF_SWITCH_PIN				PIN_PA13
#define RF_SWITCH_ACTIVE             true
#define RF_SWITCH_INACTIVE	        !RF_SWITCH_ACTIVE
/** @} */

/** \name TCXO PWR Pin definitions
 *  @{ */
#define TCXO_PWR_PIN				PIN_PB03
#define TCXO_PWR_ACTIVE             true
#define TCXO_PWR_INACTIVE	        !TCXO_PWR_ACTIVE
/** @} */
#define RFSW_PWR_PIN				PIN_PA28
#define RFSW_PWR_ACTIVE             true
#define RFSW_PWR_INACTIVE	        !RFSW_PWR_ACTIVE

/**
 * \name LED #0 definitions
 *
 * Wrapper macros for LED0, to ensure common naming across all Xplained Pro
 * boards.
 *
 *  @{ */
#define LED_0_NAME                "LED0 (yellow)"
#define LED_0_PIN                 LED0_PIN
#define LED_0_ACTIVE              LED0_ACTIVE
#define LED_0_INACTIVE            LED0_INACTIVE
#define LED0_GPIO                 LED0_PIN
#define LED0                      LED0_PIN

#define LED_0_PWM3CTRL_MODULE     TCC0
#define LED_0_PWM3CTRL_CHANNEL    3
#define LED_0_PWM3CTRL_OUTPUT     3
#define LED_0_PWM3CTRL_PIN        PIN_PA19F_TCC0_WO3
#define LED_0_PWM3CTRL_MUX        MUX_PA19F_TCC0_WO3
#define LED_0_PWM3CTRL_PINMUX     PINMUX_PA19F_TCC0_WO3
/** @} */

/**
 * \name LED #1 definitions
 *
 * Wrapper macros for LED1, to ensure common naming across all Xplained Pro
 * boards.
 *
 *  @{ */
#define LED_1_NAME                "LED1 (Green)"
#define LED_1_PIN                 LED1_PIN
#define LED_1_ACTIVE              LED1_ACTIVE
#define LED_1_INACTIVE            LED1_INACTIVE
#define LED1_GPIO                 LED1_PIN
#define LED1                      LED1_PIN

#define LED_1_PWM2CTRL_MODULE     TCC0
#define LED_1_PWM2CTRL_CHANNEL    2
#define LED_1_PWM2CTRL_OUTPUT     2
#define LED_1_PWM2CTRL_PIN        PINMUX_PA18F_TCC0_WO2
#define LED_1_PWM2CTRL_MUX        MUX_PA18F_TCC0_WO2
#define LED_1_PWM2CTRL_PINMUX     PINMUX_PA18F_TCC0_WO2
/** @} */

/** Number of on-board LEDs */
#define LED_COUNT                 2


/**
 * \name Button #0 definitions
 *
 * Wrapper macros for SW0, to ensure common naming across all Xplained Pro
 * boards.
 *
 *  @{ */
/*#define BUTTON_0_NAME             "SW0"
#define BUTTON_0_PIN              SW0_PIN
#define BUTTON_0_ACTIVE           SW0_ACTIVE
#define BUTTON_0_INACTIVE         SW0_INACTIVE
#define BUTTON_0_EIC_PIN          SW0_EIC_PIN
#define BUTTON_0_EIC_MUX          SW0_EIC_MUX
#define BUTTON_0_EIC_PINMUX       SW0_EIC_PINMUX
#define BUTTON_0_EIC_LINE         SW0_EIC_LINE*/
/** @} */

/** Number of on-board buttons */
#define BUTTON_COUNT 1

/** \name Extension header #1 pin definitions
 *  @{
 */
#define EXT1_PIN_3                PIN_PA06
#define EXT1_PIN_4                PIN_PA07
#define EXT1_PIN_5                PIN_PA08
#define EXT1_PIN_6                PIN_PA28
#define EXT1_PIN_7                PIN_PA18
#define EXT1_PIN_8                PIN_PA19
#define EXT1_PIN_9                PIN_PA22
#define EXT1_PIN_10               PIN_PA15
#define EXT1_PIN_11               PIN_PA16
#define EXT1_PIN_12               PIN_PA17
#define EXT1_PIN_13               PIN_PA05
#define EXT1_PIN_14               PIN_PA04
#define EXT1_PIN_15               PIN_PA23
#define EXT1_PIN_16               PIN_PB22
#define EXT1_PIN_17               PIN_PB02
#define EXT1_PIN_18               PIN_PB23
/** @} */

/** \name Extension header #1 pin definitions by function
 *  @{
 */
#define EXT1_PIN_ADC_0            EXT1_PIN_3
#define EXT1_PIN_ADC_1            EXT1_PIN_4
#define EXT1_PIN_GPIO_0           EXT1_PIN_5
#define EXT1_PIN_GPIO_1           EXT1_PIN_6
#define EXT1_PIN_PWM_0            EXT1_PIN_7
#define EXT1_PIN_PWM_1            EXT1_PIN_8
#define EXT1_PIN_IRQ              EXT1_PIN_9
#define EXT1_PIN_I2C_SDA          EXT1_PIN_11
#define EXT1_PIN_I2C_SCL          EXT1_PIN_12
#define EXT1_PIN_UART_RX          EXT1_PIN_13
#define EXT1_PIN_UART_TX          EXT1_PIN_14
#define EXT1_PIN_SPI_SS_1         EXT1_PIN_10
#define EXT1_PIN_SPI_SS_0         EXT1_PIN_15
#define EXT1_PIN_SPI_MOSI         EXT1_PIN_16
#define EXT1_PIN_SPI_MISO         EXT1_PIN_17
#define EXT1_PIN_SPI_SCK          EXT1_PIN_18
/** @} */

/** \name Extension header #1 ADC definitions
 *  @{
 */
#define EXT1_ADC_MODULE           ADC
#define EXT1_ADC_6_CHANNEL        6
#define EXT1_ADC_6_PIN            PIN_PA06B_ADC_AIN6
#define EXT1_ADC_6_MUX            MUX_PA06B_ADC_AIN6
#define EXT1_ADC_6_PINMUX         PINMUX_PA06B_ADC_AIN6
#define EXT1_ADC_7_CHANNEL        7
#define EXT1_ADC_7_PIN            PIN_PA07B_ADC_AIN7
#define EXT1_ADC_7_MUX            MUX_PA07B_ADC_AIN7
#define EXT1_ADC_7_PINMUX         PINMUX_PA07B_ADC_AIN7
/** @} */
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

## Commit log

2020-04-12 Penguino 4360 files added
    Dedicated Repo for the 4260 version
    [BOM-Penguino-Feather-4260-v1.ods, BOM-Penguino-Feather-4260-v1.xlsx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]
2020-10-29 doc: Folder structure update
    [BOM-Penguino-Feather-4260-v1.ods, BOM-Penguino-Feather-4260-v1.xlsx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]
2020-10-29 sch, pcb: v1.2 updates
    [BOM-Penguino-Feather-4260-v1.ods, BOM-Penguino-Feather-4260-v1.xlsx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]
2020-10-29 lib: directory updates
    [radk4260-pcb.kicad_pcb, radk4260-pcb.step, rak4260-freeCad-2.FCStd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]
2020-12-16 fix: RGB LED pin mapping update
